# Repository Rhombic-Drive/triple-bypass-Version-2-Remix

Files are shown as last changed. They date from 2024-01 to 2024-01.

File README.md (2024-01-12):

# Triple Bypass Version 2
This is a redesign of the fantastic 3bp from dbElectronics.  The goal of this project was to take the initial design and accommodate all models on one pcb without the need to swap parts. It was a team effort between myself, Retrorgb, and Jose Cruz who did the majorty of the testing. Ace, FirebrandX and Mobiusstriptech all were part of the group that helped with the redesign and added various ideas and suggestions that lead to the final product.  The audio adjustment work was done with the help of the mdFourier tool by Artemio Urbina found here - 
https://github.com/ArtemioUrbina/MDFourier.  Artemio and Bfbii stayed up many late nights and helped me run mdFourier to get the levels to match as close as we could to a model 1 va3 genesis.

From zaxour:
Modified version of Tian Feng/dB_Electronics triple bypass v2 board

Incorporates 5.6k pull up resistors for the RGB lines, as Model 1 3BP installs lift the VDP pins to isolate them from the Genesis/MD PCB. Based on research by Tian Feng, and subsequently verified by myself by looking at all available schematics for the Model 1 Genesis/MD, this causes a loss of fidelity in color transitions.

# Installation Instructions

Currently I suggest using the Audio installation instructions from the mega amp 2.0
http://www.sega-16.com/forum/showthread.php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!

For rgb bypass instructions, please see https://www.retrorgb.com/genesistriplebypass.html for now. I will continue working on getting more up-to-date instructions.

# Confirmed Working
The current version of this is working with no issues and has been tested and measured with mdFourier. There are still some systems where the pull down jumpers have not been confirmed.  If you notice any issues, please let me know.
# Design Files
I designed this using the online software tool Easyeda. While I have made the file open for people to edit, I have not yet been able to allow for the files to be truly open source.  This is a work in progress and if I have to remake everything from scratch in Kicad. The files here will always be the most up to date versions. 
# Change Log 17/03/2020
I have added a kicad file to the folder.  it looks ok but I still see some issues with ground layers.  I am new to kicad but this pretty damn close.  As it stands, I still recommend using the current gerber files to send to a pcd fab.  The design files are good to go if you want to to change or modify the design.  
# Change Log 06/03/2020
- Changed the jumper settings on the silk screen to match new info from Jose Cruz that the model 2 va4 has all of the 75 ohm pulldowns on the Genesis. Nothing needs to be changed on the previous versions.  Just take note when installing in a model 2 va4.
# Change Log from V1
 - Added jumpers so that all pulldowns could be enabled or disabled without switching parts.
 - Added AC coupling capacitors on the input of the ths7374 to accommodate for systems that we have not measured or installed in yet.
 - Changed the op amp to a soic8 footprint to accommodate a larger variety of possible op amps.
 - Changed the op amp to a tl972 low noise op amp.
 - Lowered the overall volume and increased resistance to try and alleviate some of the clipping in the louder games.
 - Changed the resistor values and numbering to try and fit on the smaller board.
 - Changed audio and video capacitors to tantalum to accommodate for a bottom mount. 
 - Adjusted and tested installation in a model 1 Genesis. 
 - Increased the audio output capacitors to 47uf.
 - Shrunk the overall size and move the din to the middle of the board to try to avoid the power jacks on a bottom install. 
 - Changed the Low pass filter to a solder jumper that will enable when it is jumped.

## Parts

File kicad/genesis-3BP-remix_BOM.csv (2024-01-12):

Designator | Footprint | Quantity | Designation | Supplier and ref
C1,C2,C3,C4,C5,C6,C20 | C_0603_1608Metric | 7 | 0.1u/50V | C0603C104M5RACTU
C10,C11,C12,C13,C14,C15 | C_0603_1608Metric | 6 | 1u/16V | C0603C105K4PACTU
C17 | CP_EIA-3216-18_Kemet-A | 1 | 10u/10V | TAJA106K016RNJV
C18,C19 | C_0603_1608Metric | 2 | 150p/50V | CL10C151JB8NFNC
C21,C22 | CP_EIA-3528-15_AVX-H | 2 | 47u/10V | TAJB476M010TNJ
C7 | C_1210_3225Metric | 1 | 22u/10V | C3225X7R1A226K230AC
C8 | CP_EIA-3528-15_AVX-H | 1 | 220u/6.3V | TCOB0J227M8R-EN1
C9,C16 | C_0805_2012Metric | 2 | 10u/10V | EMK212BJ106KG-T
R1,R12,R15,R19 | R_0603_1608Metric | 4 | 2.20k | RK73H1JTTD2201F
R10 | R_0603_1608Metric | 1 | 4.7k | RK73H1JTTD4701F
R11,R13,R14,R17,R18 | R_0603_1608Metric | 5 | 75R | RK73H1JTTDD75R0F
R16 | R_0603_1608Metric | 1 | 750R | CR0603-FX-7500ELF
R2,R3,R4,R5,R38,R39,R40 | R_0603_1608Metric | 7 | 5.62k | RK73H1JTTD5621F
R20,R21,R22,R23,R24,R25 | R_0603_1608Metric | 6 | 210k | RK73H1JTTD2103F
R26,R27,R30,R33 | R_0603_1608Metric | 4 | 10.0k | RK73H1JTTD1002F
R28,R31 | R_0603_1608Metric | 2 | 130k | CR0603-FX-1303ELF
R29,R32 | R_0603_1608Metric | 2 | 100k | RK73H1JTTD1003F
R34,R35 | R_0603_1608Metric | 2 | 300k | RK73H1JTTD3003F
R36,R37 | R_0603_1608Metric | 2 | 330R | RK73H1JTTD3300F
R6,R7,R8,R9 | R_0603_1608Metric | 4 | 1k | RK73H1JTTD1001F
U1 | TSSOP-14_4.4x5mm_P0.65mm | 1 | THS7374IPWR | THS7374IPWR
U2 | SOIC-8_3.9x4.9mm_P1.27mm | 1 | TL972IDR | TL972IDR

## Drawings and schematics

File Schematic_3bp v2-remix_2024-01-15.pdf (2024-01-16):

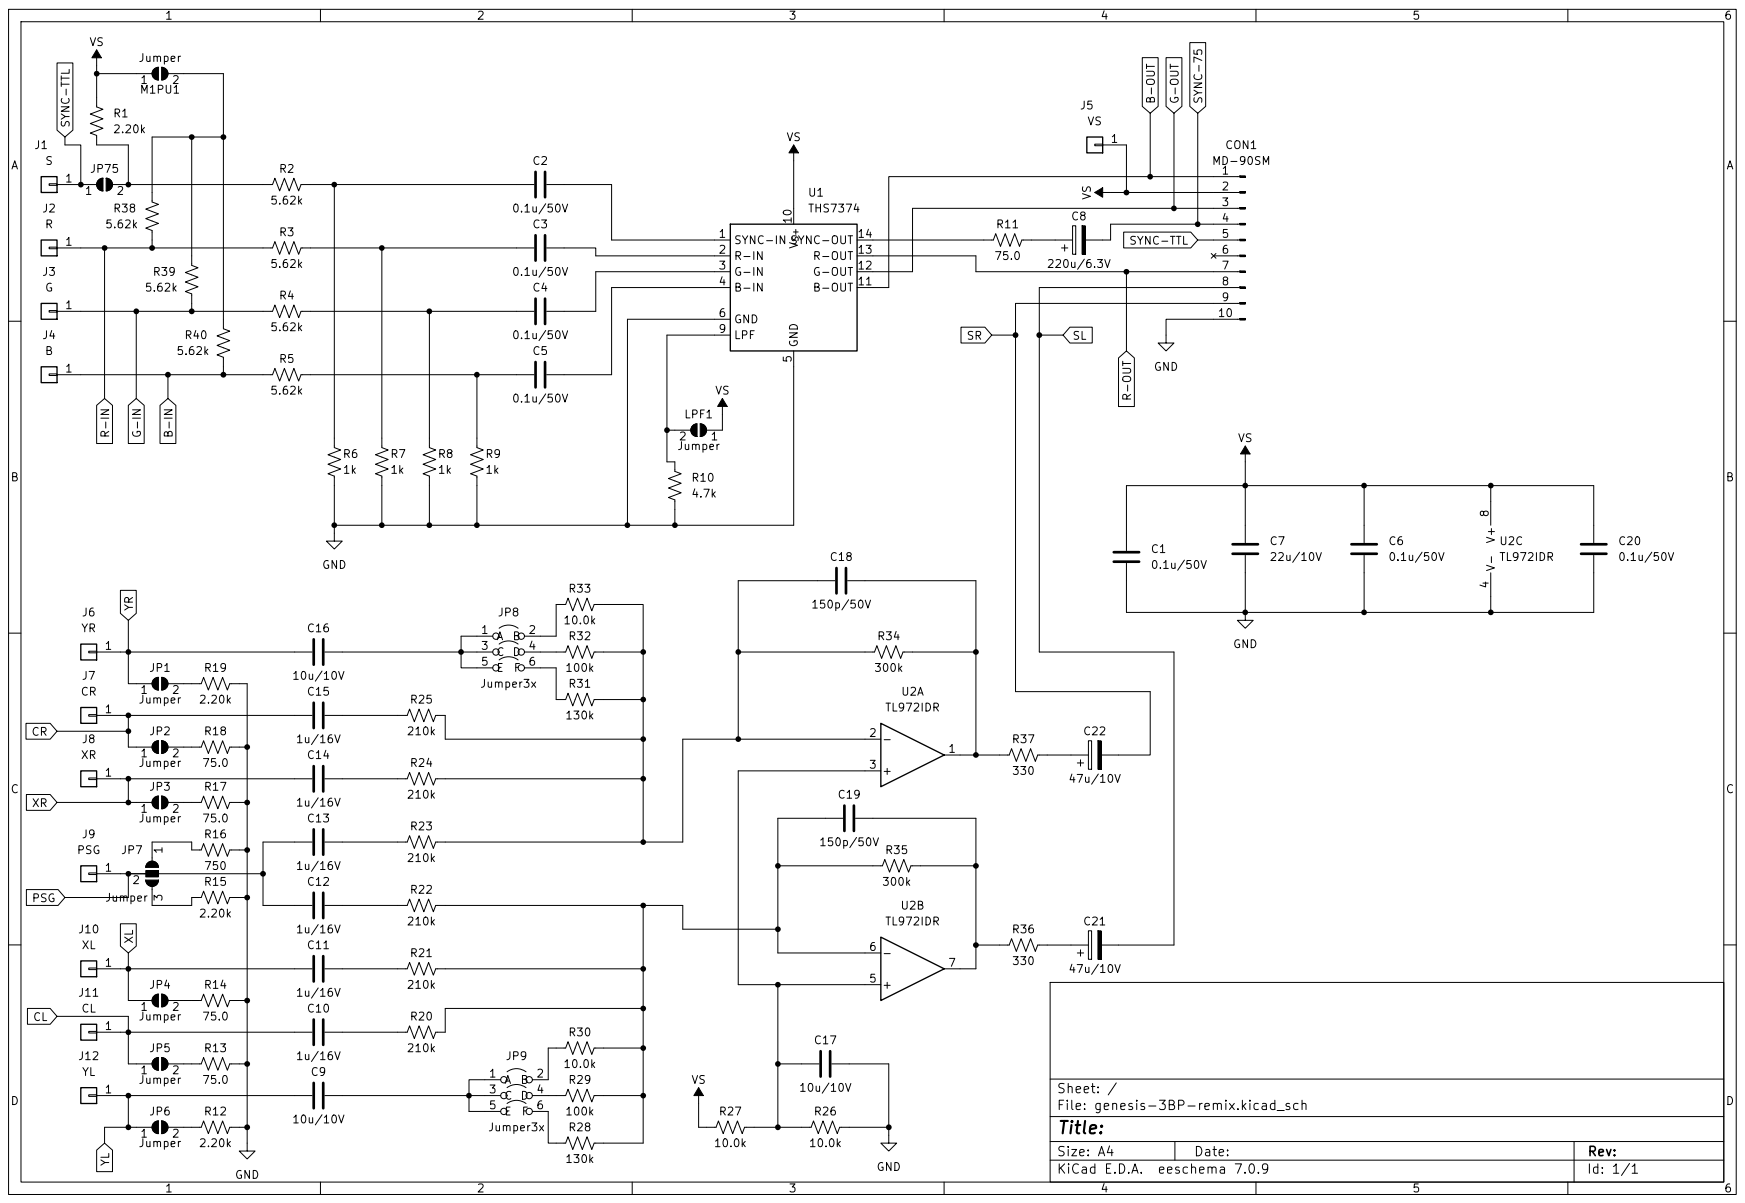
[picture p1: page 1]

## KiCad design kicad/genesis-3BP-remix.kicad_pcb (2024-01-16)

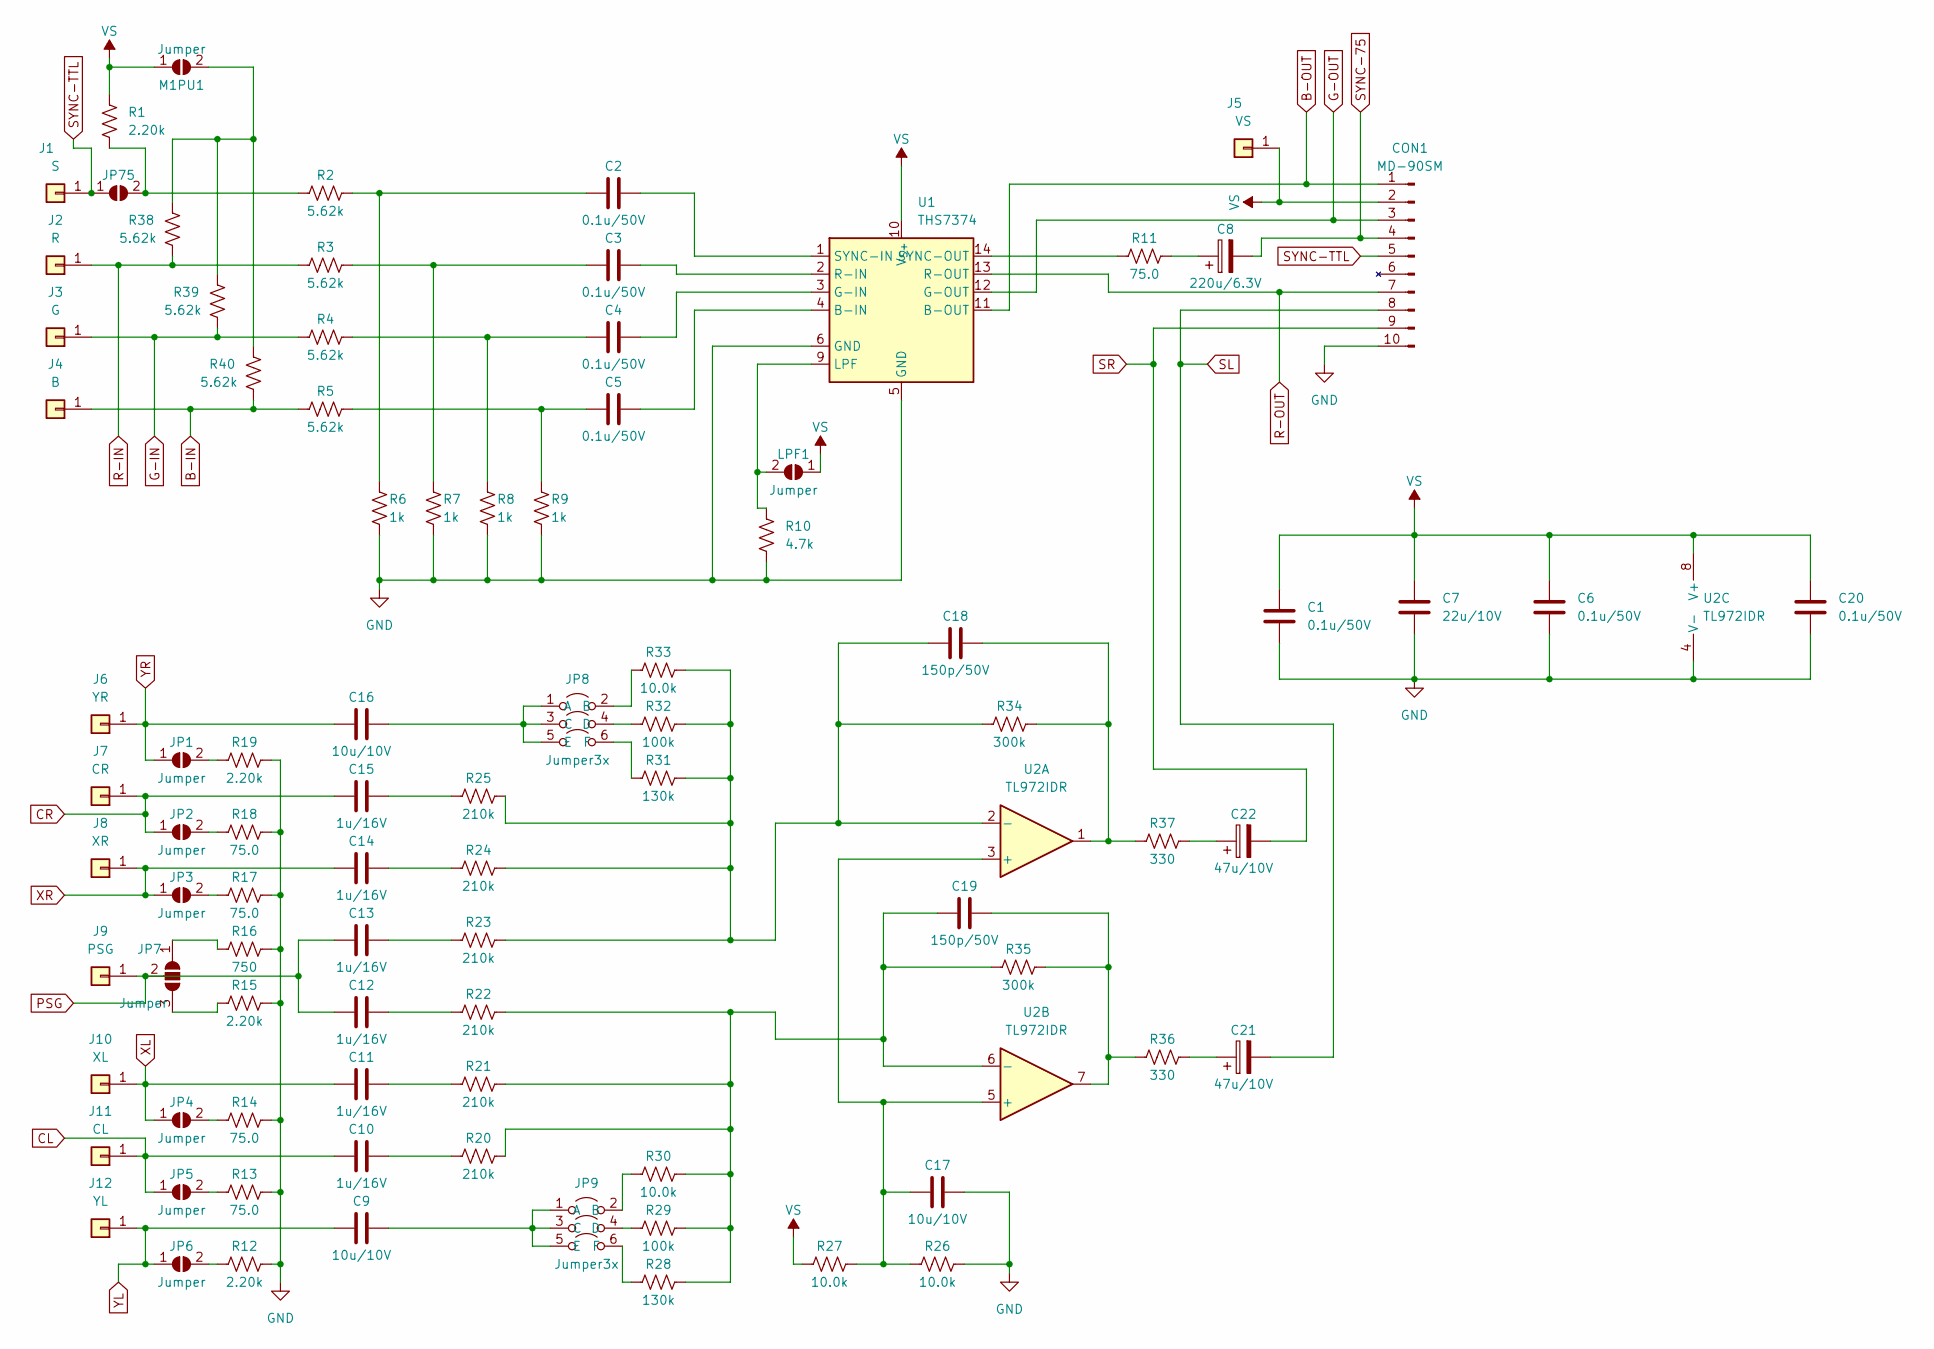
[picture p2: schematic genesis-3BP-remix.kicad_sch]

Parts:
C1, C2, C3, C4, C5, C6, C20: 0.1u/50V; C_0603_1608Metric
C7: 22u/10V; C_1210_3225Metric
C8: 220u/6.3V; CP_EIA-3528-15_AVX-H
C9, C16: 10u/10V; C_0805_2012Metric
C10, C11, C12, C13, C14, C15: 1u/16V; C_0603_1608Metric
C17: 10u/10V; CP_EIA-3216-18_Kemet-A
C18, C19: 150p/50V; C_0603_1608Metric
C21, C22: 47u/10V; CP_EIA-3528-15_AVX-H
CON1: MD-90SM
J1: S; Solder Pad
J2: R; Solder Pad
J3: G; Solder Pad
J4: B; Solder Pad
J5: VS; Solder Pad
J6: YR; Solder Pad
J7: CR; Solder Pad
J8: XR; Solder Pad
J9: PSG; Solder Pad
J10: XL; Solder Pad
J11: CL; Solder Pad
J12: YL; Solder Pad
JP1, JP2, JP3, JP4, JP5, JP6, JP75: Jumper; Jumper Pad 2
JP7: Jumper; Jumper Pad 3
JP8, JP9: Jumper3x; Triple Jumper
LPF1: Jumper; Jumper Pad 2
M1PU1: Jumper; Jumper Pad 2
R1, R12, R15, R19: 2.20k; R_0603_1608Metric
R2, R3, R4, R5, R38, R39, R40: 5.62k; R_0603_1608Metric
R6, R7, R8, R9: 1k; R_0603_1608Metric
R10: 4.7k; R_0603_1608Metric
R11, R13, R14, R17, R18: 75.0; R_0603_1608Metric
R16: 750; R_0603_1608Metric
R20, R21, R22, R23, R24, R25: 210k; R_0603_1608Metric
R26, R27, R30, R33: 10.0k; R_0603_1608Metric
R28, R31: 130k; R_0603_1608Metric
R29, R32: 100k; R_0603_1608Metric
R34, R35: 300k; R_0603_1608Metric
R36, R37: 330; R_0603_1608Metric
U1: THS7374; TSSOP-14_4.4x5mm_P0.65mm
U2: TL972IDR; SOIC-8_3.9x4.9mm_P1.27mm

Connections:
B-IN: J4.1, R5.1, R40.1
B-OUT: CON1.1, U1.11 (B-OUT)
CL: C10.1, J11.1, JP5.1 (A)
CR: C15.1, J7.1, JP2.1 (A)
G-IN: J3.1, R4.1, R39.1
G-OUT: CON1.3, U1.12 (G-OUT)
GND: C1.2, C6.1, C7.1, C17.2, C20.1, CON1.10, R6.1, R7.1, R8.1, R9.1, R10.1, R12.2, R13.2, R14.2, R15.2, R16.2, R17.2, R18.2, R19.2, R26.2, U1.5 (GND), U1.6 (GND), U2.4 (V-)
unnamed: C2.1, R2.2, R6.2
unnamed: C3.1, R3.2, R7.2
unnamed: C4.1, R4.2, R8.2
unnamed: C5.1, R5.2, R9.2
unnamed: C8.1, R11.1
unnamed: C10.2, R20.1
unnamed: C11.2, R21.1
unnamed: C12.2, R22.1
unnamed: C13.2, R23.1
unnamed: C14.2, R24.1
unnamed: C15.2, R25.1
unnamed: C18.2, R34.2, R37.1, U2.1
unnamed: C19.2, R35.2, R36.1, U2.7
unnamed: C21.1, R36.2
unnamed: C22.1, R37.2
unnamed: JP1.2 (B), R19.1
unnamed: JP2.2 (B), R18.1
unnamed: JP3.2 (B), R17.1
unnamed: JP4.2 (B), R14.1
unnamed: JP5.2 (B), R13.1
unnamed: JP6.2 (B), R12.1
unnamed: JP7.1 (A), R16.1
unnamed: JP7.3 (B), R15.1
unnamed: C16.2, JP8.1 (A), JP8.3 (C), JP8.5 (E)
unnamed: JP8.2 (B), R33.1
unnamed: JP8.4 (D), R32.1
unnamed: JP8.6 (F), R31.1
unnamed: C9.2, JP9.1 (A), JP9.3 (C), JP9.5 (E)
unnamed: JP9.2 (B), R30.1
unnamed: JP9.4 (D), R29.1
unnamed: JP9.6 (F), R28.1
unnamed: JP75.2 (B), R1.1, R2.1
unnamed: LPF1.2 (B), R10.2, U1.9 (LPF)
unnamed: M1PU1.2 (B), R38.2, R39.2, R40.2
unnamed: C5.2, U1.4 (B-IN)
unnamed: C4.2, U1.3 (G-IN)
unnamed: C3.2, U1.2 (R-IN)
unnamed: C2.2, U1.1 (SYNC-IN)
unnamed: R11.2, U1.14 (SYNC-OUT)
unnamed: C17.1, R26.1, R27.2, U2.3 (+), U2.5 (+)
unnamed: C18.1, R23.2, R24.2, R25.2, R31.2, R32.2, R33.2, R34.1, U2.2 (-)
unnamed: C19.1, R20.2, R21.2, R22.2, R28.2, R29.2, R30.2, R35.1, U2.6 (-)
PSG: C12.1, C13.1, J9.1, JP7.2 (C)
R-IN: J2.1, R3.1, R38.1
R-OUT: CON1.7, U1.13 (R-OUT)
SL: C21.2, CON1.8
SR: C22.2, CON1.9
SYNC-75: C8.2, CON1.4
SYNC-TTL: CON1.5, J1.1, JP75.1 (A)
VS: C1.1, C6.2, C7.2, C20.2, CON1.2, J5.1, LPF1.1 (A), M1PU1.1 (A), R1.2, R27.1, U1.10 (V_{S+}), U2.8 (V+)
XL: C11.1, J10.1, JP4.1 (A)
XR: C14.1, J8.1, JP3.1 (A)
YL: C9.1, J12.1, JP6.1 (A)
YR: C16.1, J6.1, JP1.1 (A)

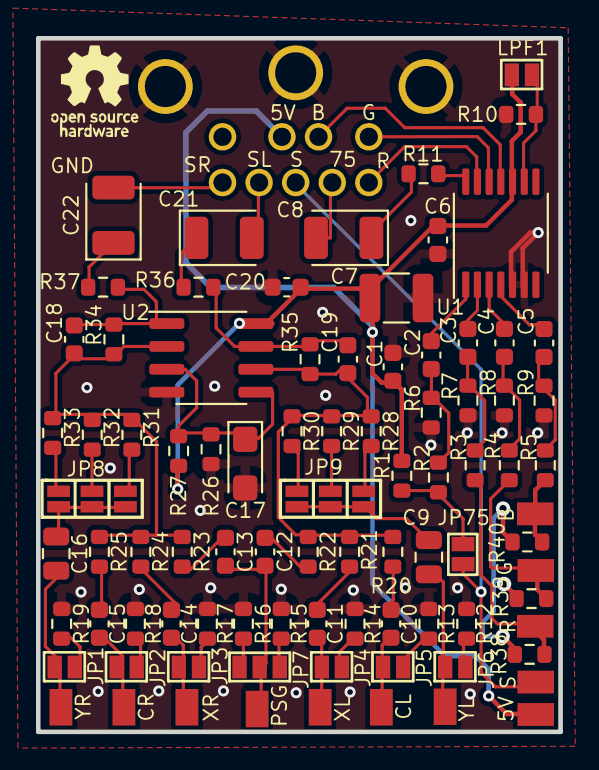
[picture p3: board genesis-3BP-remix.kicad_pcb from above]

Board: 2 copper layers, 29.0 x 38.5 mm, 91 parts (1 on the bottom side), 61 nets.

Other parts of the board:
G: LOGO; OSHW-LOGO_5MM
G#2: LOGO; OSHW-LOGO_5MM

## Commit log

2024-01-12 Updated schematic
2024-01-12 Adding new KiCad files
    [genesis-3BP-remix.kicad_pcb, genesis-3BP-remix.kicad_sch]
2024-01-12 Delete kicad/Schematic_3bp v2-remix_2024-01-12.png
    Duplicate
2024-01-12 New BOM
    [genesis-3BP-remix_BOM.csv]
2024-01-12 Update cap pad change
    [genesis-3BP-remix.kicad_pcb, genesis-3BP-remix.kicad_sch, genesis-3BP-remix_BOM.csv]
2024-01-12 Update gerbers
2024-01-16 Update BOM
2024-01-16 Update silkscreen placement
    [genesis-3BP-remix.kicad_pcb, genesis-3BP-remix.kicad_sch]
2024-01-16 New schematic

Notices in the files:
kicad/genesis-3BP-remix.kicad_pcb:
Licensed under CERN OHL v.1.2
